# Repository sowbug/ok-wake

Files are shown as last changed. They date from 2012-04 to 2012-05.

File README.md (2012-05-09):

OK Wake
=======

[OK Wake](http://www.sowbug.com/ok-wake) is a device that lets pre-literate kids know it's OK to get out of bed.

Copyright © 2012 Mike Tsao.

This project started with a lunchtime conversation with a friend whose kids are too young to read, but not too young to get out of bed at the crack of dawn and wake up their parents. We wondered whether a little blinking light would be a satisfactory signal to keep the kids in bed until the designated hour.

Thus was born the OK Wake. It divides the day into three sections: night, twilight, and dawn. Most of the 24-hour cycle is night, and the device does nothing. If wake-up time is 6am, then twilight would start at 5:30am with a slow red blink, gradually increasing in frequency until dawn at 6am, when the blink changes to a green “breathing” blink. Dawn continues for 10 minutes, and then night resumes.

While working on the feature set, I had some very intricate ideas for dealing with Daylight Saving Time. Either I’d just handle it (meaning the kids would be confused by the abrupt shift twice a year), or I’d do a gradual shift in the week or so leading up to the time change. It got complicated, especially when I thought about the case where the family traveled to a different timezone. I finally decided I was overthinking the problem, and added a button. Pressing the button sets the alarm to 12 hours from the current time (e.g., press at 6pm to wake at 6am). I want to call this the antipode, as it’s the opposite point on a circular clock, but I think I’m misusing that term. I think the 6pm/6am solution is simple and elegant; as a parent I know kids want to wake up around 6am, and 6pm is right around the time parents are thinking they’d be totally OK with the kids going to bed right now.

The circuit is based on an ATtiny25 microcontroller and a Philips/NXP PCF8523 real-time clock chip. I chose the ‘8523 for two reasons: first, it is not the Maxim DS1307, which is shockingly expensive for a chip that’s basically a digital counter; and second, because it uses I2C, which I wanted to learn about.

Early in the design phase, I concluded that picking the ‘8523 eliminated my current favorite AVR, the ATtiny13a, because that chip didn’t support I2C. But as I later learned, the ATtiny25 doesn’t really support I2C either, except to the extent that it has a USART that can be tricked into assisting with I2C bit-banging. In the end I didn’t even use the USART anyway, instead relying on a fantastic small I2C library that uses two GPIO pins. But I’m happy I had the ‘25 rather than the ‘13a, because I used up about 1,800 of the 2KB program space, and wouldn’t have had much fun trying to squeeze that into the 1KB space of the ‘13a.

The firmware took one weekend day and two nights to write, which felt like a long time for a fairly simple set of features. I started out using an Arduino as the hardware platform, which was marginally useful for getting up and running, but eventually I threw out all that code when rewriting for the ‘25. The most frustrating part by far was dealing with the packed BCD (binary-coded decimal) that appears to be commonplace with RTC chips. I did just enough time math that I had to write bcd add/subtract routines (fortunately there are canonical bit-twiddling solutions on the web), and BCD-to-time-aware-decimal conversion routines. Unit tests helped a lot here.

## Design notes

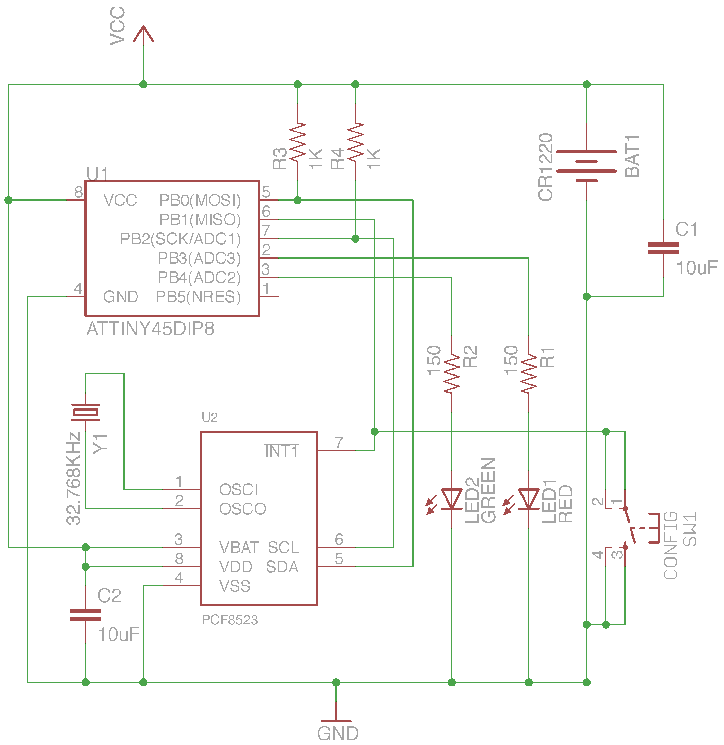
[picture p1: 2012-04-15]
ok-wake.sch.png

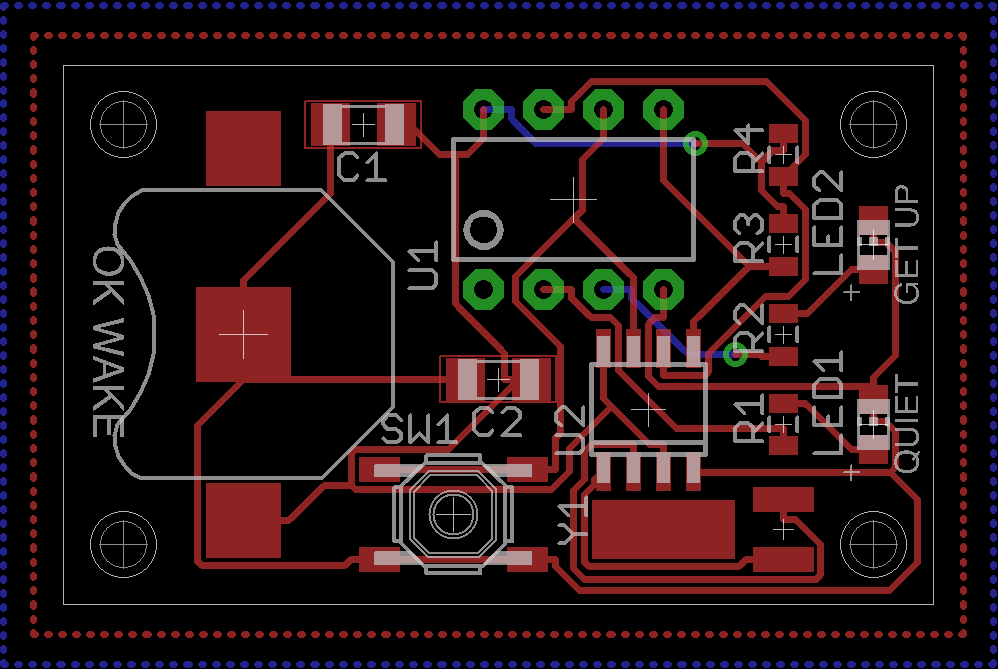
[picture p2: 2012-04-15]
ok-wake.brd.png

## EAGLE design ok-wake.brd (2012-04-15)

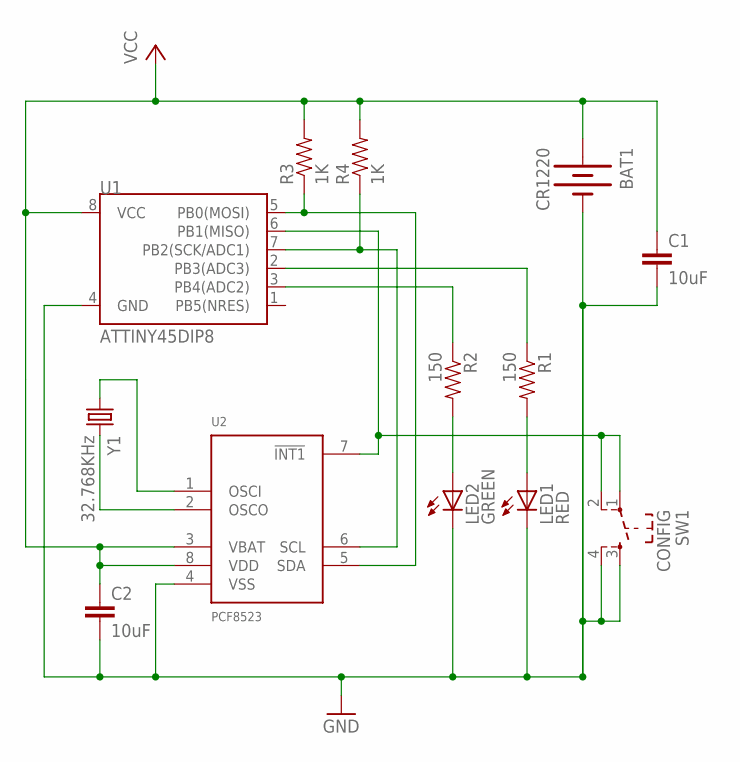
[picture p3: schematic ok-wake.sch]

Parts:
BAT1: CR1220; BATTCON_12MM
C1, C2: 10uF; 1206
LED1: RED; CHIP-LED0805
LED2: GREEN; CHIP-LED0805
R1, R2: 150; 0805
R3, R4: 1K; 0805
SW1: CONFIG; SW_TACT_SMALL
U1: ATTINY45DIP8; DIP08
U2: PCF8523; SO8
Y1: 32.768KHz; CRYSTAL-32KHZ-SMD

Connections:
!INT1: SW1.1, SW1.2, U1.6 (PB1(MISO)), U2.7 (!INT1)
GND: BAT1.GND (-), C1.2, C2.2, LED1.C, LED2.C, SW1.3, SW1.4, U1.4 (GND), U2.4 (VSS)
LED1-LO: LED1.A, R1.2
LED1-OUT: R1.1, U1.2 (PB3(ADC3))
LED2-LO: LED2.A, R2.2
LED2-OUT: R2.1, U1.3 (PB4(ADC2))
OSCI: U2.1 (OSCI), Y1.X1 (1)
OSCO: U2.2 (OSCO), Y1.X2 (2)
SCL/SCK: R4.1, U1.7 (PB2(SCK/ADC1)), U2.6 (SCL)
SDA/MOSI: R3.1, U1.5 (PB0(MOSI)), U2.5 (SDA)
VCC: BAT1.PWR@1 (+), C1.1, C2.1, R3.2, R4.2, U1.8 (VCC), U2.3 (VBAT), U2.8 (VDD)

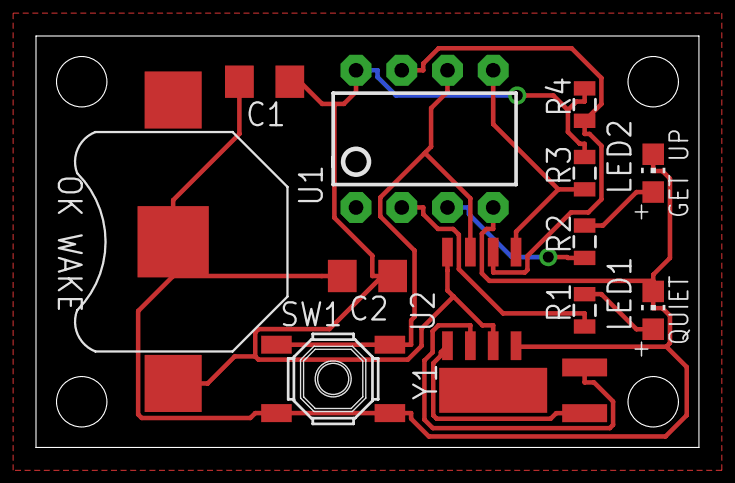
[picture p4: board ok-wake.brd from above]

Board: 2 copper layers, 36.8 x 22.9 mm, 13 parts (0 on the bottom side), 11 nets.

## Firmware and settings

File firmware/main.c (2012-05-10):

/*
 * OK Wake
 * https://github.com/sowbug/ok-wake/
 *
 * Copyright (c) 2012 Mike Tsao.
 */

#include "attinyx5.h"
#include "bcd.h"
#include "eeprom.h"
#include "i2cmaster.h"

#include <avr/io.h>
#include <avr/sleep.h>
#include <inttypes.h>
#include <util/delay.h>

enum {
  STATE_INIT = 0,
  STATE_NIGHT,
  STATE_TWILIGHT,
  STATE_DAWN,
};

// How long before wake time we should start blinking lights.
const uint8_t TWILIGHT_MINUTES = 30;

// How long after wake time we should keep blinking lights.
const uint8_t DAWN_MINUTES = 30;

// The time when it's OK for kid to get up
uint16_t wake_time_bcd;

// The current time
uint16_t time_bcd;

// How many seconds before next blink
uint8_t twilight_counter_top;

// How long until halving counter_top
uint8_t twilight_next_minute_level;

// Side effect: clears value.
static uint8_t _was_button_pressed;
uint8_t was_button_pressed() {
  uint8_t result = _was_button_pressed;
  _was_button_pressed = 0;
  return result;
}

static void flicker_leds(uint8_t count) {
  while (count--) {
    quiet_on();
    _delay_ms(25);
    wake_on();
    _delay_ms(25);
  }

  leds_off();
}

static void flicker_quiet(uint8_t count) {
  while (count--) {
    quiet_on();
    _delay_ms(5);
    leds_off();
    _delay_ms(45);
  }
}

static void flicker_wake(uint8_t count) {
  while (count--) {
    wake_on();
    _delay_ms(5);
    leds_off();
    _delay_ms(45);
  }
}

static void breathe_wake() {
  uint8_t cycles = 2;
  uint8_t phase = 0;
  int8_t phase_direction = 4;

  while (cycles) {
    uint8_t sweep = 0;

    while (--sweep) {
      if (sweep < phase) {
        wake_on();
      } else {
        leds_off();
      }
    }

    phase += phase_direction;

    if (phase == 0) {
      phase_direction = -phase_direction;
      cycles--;
    }
  }

  leds_off();
}

static uint8_t maybe_set_rtc_time() {
  if (!eeprom_read_byte(&kShouldSetRTC)) {
    return 0;
  }

  // Update RTC.
  uint8_t registers[7];
  eeprom_read_block(registers, &kRTCTimeCircuits, 7);
  set_rtc_time(registers);

  // Mark the time set.
  eeprom_update_byte(&kShouldSetRTC, 0);
  return 1;
}

static void read_wake_time() {
  wake_time_bcd = eeprom_read_word(&kWakeTime);
}

static void set_alarm() {
  set_rtc_alarm(add_minutes_to_bcd_time(wake_time_bcd, -TWILIGHT_MINUTES));
}

// The idea is you push the button at 6pm, and it'll set the clock for a
// wakeup time of 6am.
static void set_wake_time() {
  wake_time_bcd = add_minutes_to_bcd_time(time_bcd, MINUTES_IN_HALF_DAY);
  eeprom_update_word(&kWakeTime, wake_time_bcd);
  set_alarm();
  flicker_leds(1);
}

static uint8_t start_NIGHT() {
  set_second_interrupt(0);
  return STATE_NIGHT;
}

static uint8_t start_TWILIGHT() {
  set_second_interrupt(1);
  twilight_counter_top = 10;
  twilight_next_minute_level = TWILIGHT_MINUTES >> 1;
  return STATE_TWILIGHT;
}

static uint8_t start_DAWN() {
  set_second_interrupt(1);
  return STATE_DAWN;
}

static void power_down() {
    leds_off();
    set_sleep_mode(SLEEP_MODE_PWR_DOWN);
    enable_pin_interrupts(1);

    // Go to sleep.
    sleep_mode();

    // We've woken up.
    enable_pin_interrupts(0);
    i2c_init();

    // If we woke up and the '8523's SF and AF bits are clear, then it's
    // a safe guess the button was pressed (as opposed to the '8523's
    // /INT1 going active).
    _was_button_pressed = !clear_rtc_interrupt_flags();
}

static void handle_NIGHT() {
}

static void do_twilight_blink(int16_t minutes_left) {
  if (minutes_left <= 1) {
    flicker_quiet(1);
    flicker_wake(1);
  } else if (minutes_left <= 2) {
    flicker_quiet(2);
    flicker_wake(1);
  } else {
    flicker_quiet(1);
  }
}

static void handle_TWILIGHT(int16_t minutes_left) {
  static uint8_t counter;

  while (minutes_left < twilight_next_minute_level &&
         twilight_counter_top > 1) {
    twilight_next_minute_level >>= 1;
    twilight_counter_top >>= 1;
  }

  if (!counter--) {
    do_twilight_blink(minutes_left);
    counter = twilight_counter_top;
  }
}

static void handle_DAWN(int16_t minutes_elapsed) {
  if (minutes_elapsed < 3) {
    breathe_wake();
  } else {
    flicker_wake(1);
  }
}

static void do_i2c_diagnostics() {
  while (!is_rtc_connected()) {
    flicker_leds(2);
    _delay_ms(500);
  }

  while (!rtc_write_verify()) {
    flicker_quiet(2);
    _delay_ms(500);
  }

  breathe_wake();
}

static void init_system() {
  sei();
  init_ports();
  init_power_reduction_register();
  i2c_init();
  reset_rtc();
  stop_32768_clkout();
  do_i2c_diagnostics();

  if (maybe_set_rtc_time()) {
    flicker_leds(8);
  }

  refresh_time(&time_bcd);
  read_wake_time();
  set_alarm();
}

static uint8_t do_state_work(uint8_t state) {
  int16_t minutes_until_wake = smart_time_until_alarm(time_bcd, wake_time_bcd);
  uint8_t is_twilight = (minutes_until_wake <= TWILIGHT_MINUTES &&
                         minutes_until_wake > 0);
  uint8_t is_dawn = (minutes_until_wake > -DAWN_MINUTES &&
                     minutes_until_wake <= 0);

  if (minutes_until_wake < 0) {
    minutes_until_wake = -minutes_until_wake;
  }

  if (!is_twilight && !is_dawn && state != STATE_NIGHT) {
    state = start_NIGHT();
  }

  if (is_twilight && state != STATE_TWILIGHT) {
    state = start_TWILIGHT();
  }

  if (is_dawn && state != STATE_DAWN) {
    state = start_DAWN();
  }

  switch (state) {
  case STATE_NIGHT:
    handle_NIGHT();
    break;

  case STATE_TWILIGHT:
    handle_TWILIGHT(minutes_until_wake);
    break;

  case STATE_DAWN:
    handle_DAWN(minutes_until_wake);
    break;
  }

  return state;
}

int main(void) {
  init_system();
  uint8_t state = STATE_INIT;

  while (1) {
    if (was_button_pressed()) {
      set_wake_time();
      continue;
    }

    state = do_state_work(state);

    // We skip sleeping if the RTC is already trying to wake us up.
    if (!clear_rtc_interrupt_flags()) {
      // Wait for user to release button.
      while (is_button_pressed())
        ;

      // Power down, and we'll be woken up by /INT. This function will
      // return when we wake up again.
      power_down();

      // Now wait once again for any rising edge to pass.
      while (is_button_pressed())
        ;

      // We're awake and ready to go. Get the correct time copied locally.
      refresh_time(&time_bcd);
    }
  }
}

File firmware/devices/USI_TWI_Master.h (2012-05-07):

/*****************************************************************************
*
*
* File              USI_TWI_Master.h compiled with gcc
* Date              Friday, 10/31/08    Boo!
* Updated by        jkl
*
*
* Supported devices : All device with USI module can be used.
*                     The example is written for the ATtiny2313
*
* AppNote           : AVR310 - Using the USI module as a TWI Master
*
* This is modified to just do I2C communication on ATtiny2313 running at 
* 1MHz. Fast mode is probably possible, but would need a faster clock
* and has not been tested.
*
* 12/15/08  Added declaration of USI_TWI_Start_Memory_Read  -jkl
****************************************************************************/

//********** Defines **********//

// Defines controlling timing limits - SCL <= 100KHz.

// For use with _delay_us()
#define T2_TWI    5     // >4,7us
#define T4_TWI    4     // >4,0us

// Defines error code generating
//#define PARAM_VERIFICATION
//#define NOISE_TESTING
#define SIGNAL_VERIFY   // This should probably be on always.

/****************************************************************************
Bit and byte definitions
****************************************************************************/
#define TWI_READ_BIT  0       // Bit position for R/W bit in "address byte".
#define TWI_ADR_BITS  1       // Bit position for LSB of the slave address bits in the init byte.
#define TWI_NACK_BIT  0       // Bit position for (N)ACK bit.

// Note these have been renumbered from the Atmel Apps Note. Most likely errors are now
//    lowest numbers so they're easily recognized as LED flashes.
#define USI_TWI_NO_DATA             0x08  // Transmission buffer is empty
#define USI_TWI_DATA_OUT_OF_BOUND   0x09  // Transmission buffer is outside SRAM space
#define USI_TWI_UE_START_CON        0x07  // Unexpected Start Condition
#define USI_TWI_UE_STOP_CON         0x06  // Unexpected Stop Condition
#define USI_TWI_UE_DATA_COL         0x05  // Unexpected Data Collision (arbitration)
#define USI_TWI_NO_ACK_ON_DATA      0x02  // The slave did not acknowledge  all data
#define USI_TWI_NO_ACK_ON_ADDRESS   0x01  // The slave did not acknowledge  the address
#define USI_TWI_MISSING_START_CON   0x03  // Generated Start Condition not detected on bus
#define USI_TWI_MISSING_STOP_CON    0x04  // Generated Stop Condition not detected on bus
#define USI_TWI_BAD_MEM_READ      0x0A  // Error during external memory read

// ATtinyx5
#define DDR_USI             DDRB
#define PIN_USI             PINB
#define PIN_USI_SCL         PINB2
#define PIN_USI_SDA         PINB0
#define PORT_USI            PORTB
#define PORT_USI_SCL        PORTB2
#define PORT_USI_SDA        PORTB0

// General defines
#define TRUE  1
#define FALSE 0

//********** Prototypes **********//

void USI_TWI_Master_Initialise( void );
unsigned char USI_TWI_Start_Random_Read( unsigned char * , unsigned char );
unsigned char USI_TWI_Start_Read_Write( unsigned char * , unsigned char );
unsigned char USI_TWI_Get_State_Info( void );

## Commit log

2012-05-07 Bunch of ATtiny25 work. Not working.
    [USI_TWI_Master.h, atmega328.h, attinyx5.h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]
2012-05-07 Fixed bug (no interrupts in interrupt handler). Might be working.
    [USI_TWI_Master.h, attinyx5.c, attinyx5.h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]
2012-05-07 Reformatting, and maybe fixed a boundary condition.
    [atmega328.h, attinyx5.c, attinyx5.h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]
2012-05-08 Checkpoint - BCD work. Broken.
    [main.c, pcf8523.c]
2012-05-09 Switch over to Peter Fleury's I2C Master library.
2012-05-09 Use block i2c and eeprom access.
2012-05-09 Fixed an argument transposition error.
    [main.c, pcf8523.c]
2012-05-09 Cleanup. Fixed a likely failure-to-power-down bug in power_down().
    [USI_TWI_Master.h, attinyx5.c, attinyx5.h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]

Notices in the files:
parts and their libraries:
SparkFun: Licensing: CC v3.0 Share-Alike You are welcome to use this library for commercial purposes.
